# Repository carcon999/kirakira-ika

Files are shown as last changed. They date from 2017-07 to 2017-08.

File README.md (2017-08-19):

きらきら☆いか
===================

### 概要

『きらきら☆いか』は、残像表示が得意なLEDバーになります。

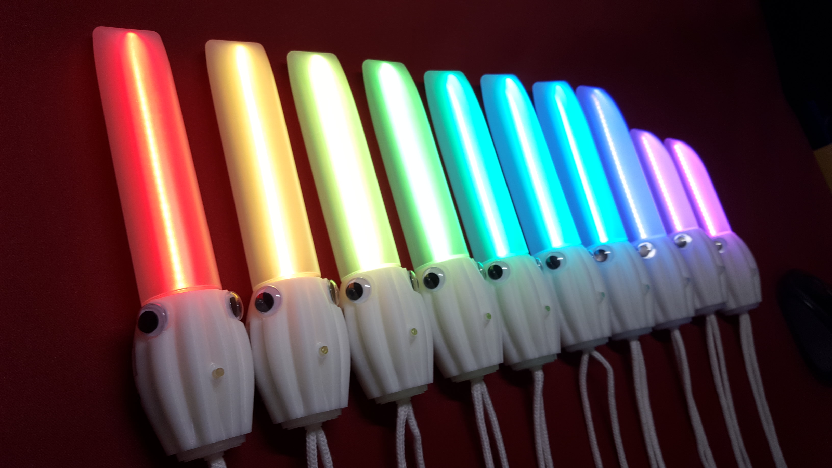
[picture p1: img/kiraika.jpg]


簡単な紹介動画はこちらです。
https://youtu.be/-Ymk3oiKI8k

### 取扱い説明書
本体の説明書になります。
[guidebook](https://github.com/carcon999/kirakira-ika/tree/master/guidebook)フォルダにPDFファイルを公開しています。  

### 回路図
ハードウェアの回路図を公開しました。
ESP-WROOM-02(ESP8266)を利用しています。LEDは3535サイズの[SK6812MINI](https://cdn-shop.adafruit.com/product-files/2686/SK6812MINI_REV.01-1-2.pdf)を利用しています。表裏合わせると最大64個のLEDを搭載できる設計です。  
[schematic](https://github.com/carcon999/kirakira-ika/tree/master/schematic)フォルダにPDFファイルを公開しています。 

### ガーバー
基板製造用のgerberを公開しました。
[gerber](https://github.com/carcon999/kirakira-ika/tree/master/gerber)フォルダに一式公開しています。基板を３面付けしたデータを公開しています。表示するには、別途Gerber Viewerが必要です。

### プログラム（本体ソースコード）
Arduino IDEでビルド可能な、本体プログラムを公開しています。
[source](https://github.com/carcon999/kirakira-ika/tree/master/source)フォルダに一式公開しています。
ビルド方法は、その中にある[README.md](https://github.com/carcon999/kirakira-ika/tree/master/source/README.md)を参照してください。

### 筐体モデルデータ
モデリングした本体の筐体データを公開しました。  
[3dmodel](https://github.com/carcon999/kirakira-ika/tree/master/3dmodel)フォルダにSTLファイルを公開しています。  
３Dプリンタで印刷することができます。  

### きら☆いか リモコン
アンドロイド端末で利用できるWi-FiリモコンはGoogle Playから[ダウンロード](https://play.google.com/store/apps/details?id=jp.gr.java_conf.approid.kiraika_remo)することができます。  

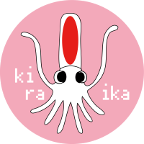
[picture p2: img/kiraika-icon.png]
  

### リモコン用ソースコード  
リモートコントロールは、 **WebSocket**が利用できるため、ブラウザ経由で制御することができます。[remotecontrol](https://github.com/carcon999/kirakira-ika/tree/master/remotecontrol)フォルダに一式公開しております。動作確認は、Chromeでのみ確認しております。
PCのWi-Fi接続先をきらきら☆いかのアクセスポイントにすることで、パソコンからコントロールすることができます。  
※こちらは、本体用のプログラムではありません。リモートコントロール用です。

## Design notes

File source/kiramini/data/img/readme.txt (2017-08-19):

画像はこのimgフォルダに配置された画像が有効になります。
有効な画像には条件がありますのでご注意ください。

１．ファイル名は、８＋３の短い名前を利用してください。
２．画像は、24bitフルカラービットマップ形式のみです。（PNGやJPGはNG)
３．画像の高さは、LED数に合わせてください。
４．画像の幅は、最大256ピクセルとします。

デフォルトで入っている画像は、下記のサイトのアイコンを一部利用させていただきました。
手頃なサイズのアイコンが揃っております。
ソザイガロー（SozaiGaro）様
http://hpgpixer.jp/

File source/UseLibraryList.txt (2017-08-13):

Use Library List

*** Arduino core for ESP8266 WiFi chip

https://github.com/esp8266/Arduino
GNU Lesser General Public License version 2.1 or (at your option) any later version.

*** ESP8266WebServer

https://github.com/esp8266/Arduino/tree/master/libraries/ESP8266WebServer

Copyright (c) 2014 Ivan Grokhotkov.
GNU Lesser General Public License version 2.1 or (at your option) any later version.

*** Software I2S library for esp8266

Copyright (c) 2015 Hristo Gochkov.
GNU Lesser General Public License version 2.1 or (at your option) any later version.

*** Library for accelerometer_MMA7760

Copyright (c) 2013 seeed technology inc.
MIT License (MIT)

*** ArduinoJson

https://bblanchon.github.io/ArduinoJson/
MIT License (MIT)

*** WebSocket Server and Client for Arduino

https://github.com/Links2004/arduinoWebSockets
GNU Lesser General Public License version 2.1 or (at your option) any later version.

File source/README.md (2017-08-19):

ビルド＆書き込み手順の説明
===================

### 注意事項

ライセンスは、[LICENSE.txt](https://raw.githubusercontent.com/carcon999/kirakira-ika/master/LICENSE.txt)をご確認ください。

# 概要

プログラムは、Arduino IDE 1.8.2でビルドし動作確認しています。  
ファームウェアを変更するには、ライブラリの準備や本体のジャンバー設定を変更する等の準備が必要になります。
手順をしっかり確認してから実施してください。ファームウェアの書き換えにはリスクを伴います。自己責任で実施してください。  

# ビルド環境の構築

## Arduino IDEをインストールする

IDEのインストール方法については、「Arduino IDE インストール」で検索することで見つけることができますので、
その手順に従ってインストールしてください。  当方では、Arduino IDE 1.8.2で検証しています。

インストール後、今回利用しているマイコンESP-WROOM-02(ESP8266)が利用できるように、ボードマネージャーにESP8266ボードをインストールする必要があります。
こちらも、ここでは詳細な説明をしませんので、「Arduino IDE ESP8266 インストール」で検索しインストールしてください。  

今回利用したバージョンは、「esp8266 by ESP8266 Commuity Version 2.3.0」になります。

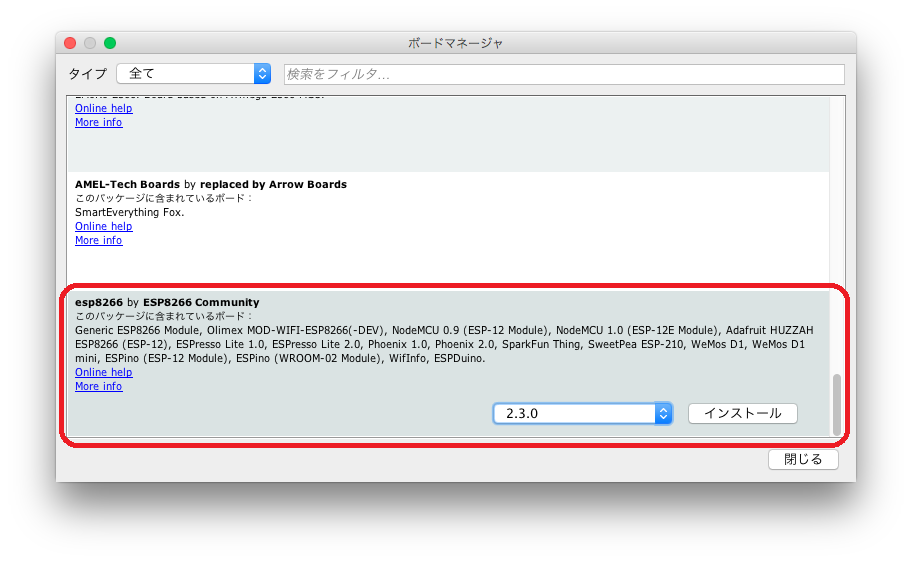
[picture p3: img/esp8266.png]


## ライブラリをインストールする

次に、利用するライブラリを２つ追加します。  
IDEの「スケッチ」→「ライブラリをインクルード」→「ライブラリを管理」を選択し、以下の２ライブラリをインストールします。

* ArduinoJson by Benolt Blanchon
* WebSockets by Markus Sattler 

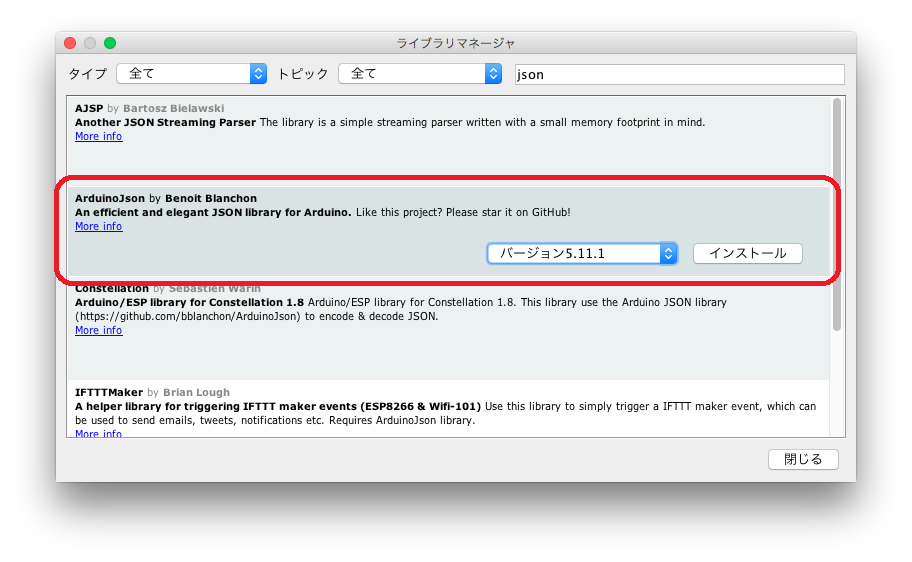
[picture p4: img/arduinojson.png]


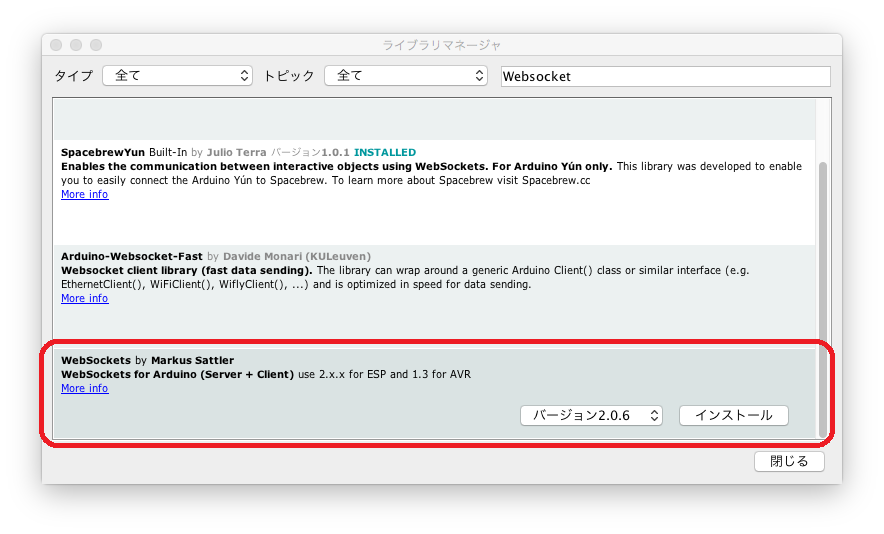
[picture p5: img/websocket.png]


## データ領域書き込みツールのインストール

データ領域（残像用の画像や設定HTMLファイル）に書き込むためには、ツール（[SPIFFSファイルシステムアップローダー](https://github.com/esp8266/arduino-esp8266fs-plugin)）
をインストールする必要があります。ツールをインストールすることで、Arduino IDEからデータ領域にデータを書き込むことができるようになります。

[SPIFFSファイルシステムアップローダー](https://github.com/esp8266/arduino-esp8266fs-plugin)をインストールしますが、インストーラは存在しないので、手動でファイルをコピーする必要があります。
幸い詳しく手順を説明しているブログがありますので、こちらを参考にしてください。

https://www.mgo-tec.com/spiffs-filesystem-uploader01-html

注意点としては、配置先の階層とフォルダ名に注意してください。下記の写真のような階層です。(画面はMacの場合です）

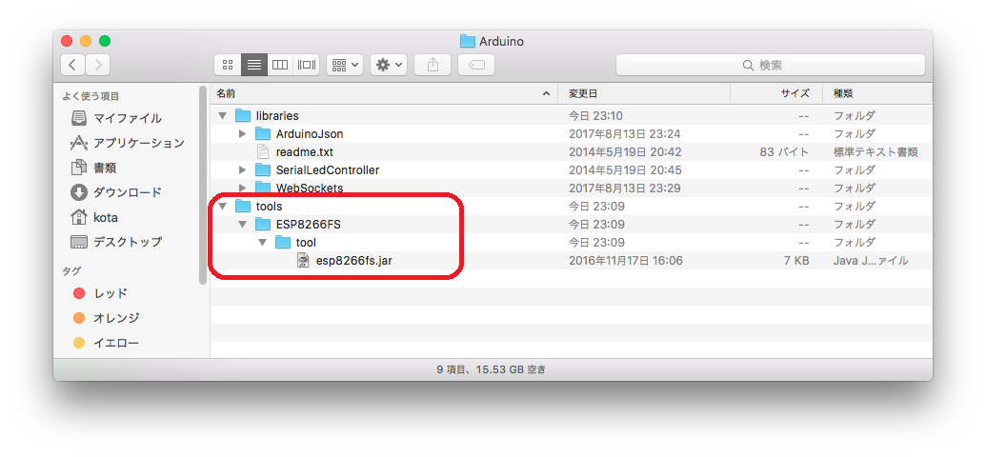
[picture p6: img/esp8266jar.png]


配置後、IDEを起動（再起動）すると、ツールメニューの中に「ESP8266 Sketch Data Upload」表示されるようになります。

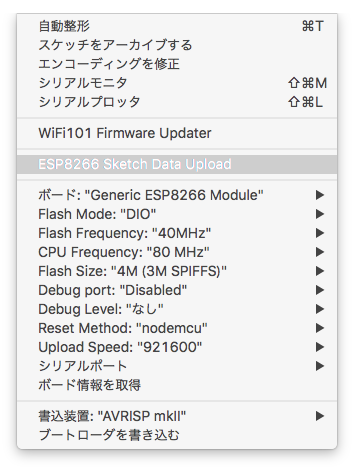
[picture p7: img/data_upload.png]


以上でツール類のインストールは全て完了しました。

# 本体側の準備（基板の取り出しとジャンパー変更）

micro USBケーブルで本体とパソコンを接続し書き換えを行いますが、そのままの状態では書き換えは行えません。
基板上のジャンパー設定を変更した上で書き換えを実施する必要があります。そのためには、本体から基板を取り出す必要がありますが、
無理な力をかけて取り出すと故障の原因ともなりますのでご注意ください。

1. 本体の電源はOFFとなっていることを確認します。

2. ネジを２か所外し、背面カバーを外します。

3. 基板を取り出します。（チューブを5度程度折り曲げると取り出しやすいです。）
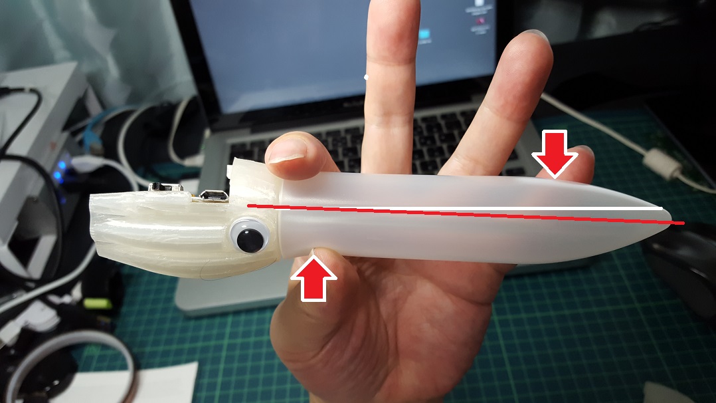
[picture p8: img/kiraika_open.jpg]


4. 取り出した基板の前面に小型のジャンパーがあり、現在は、LED側となっているのをRX側にします。
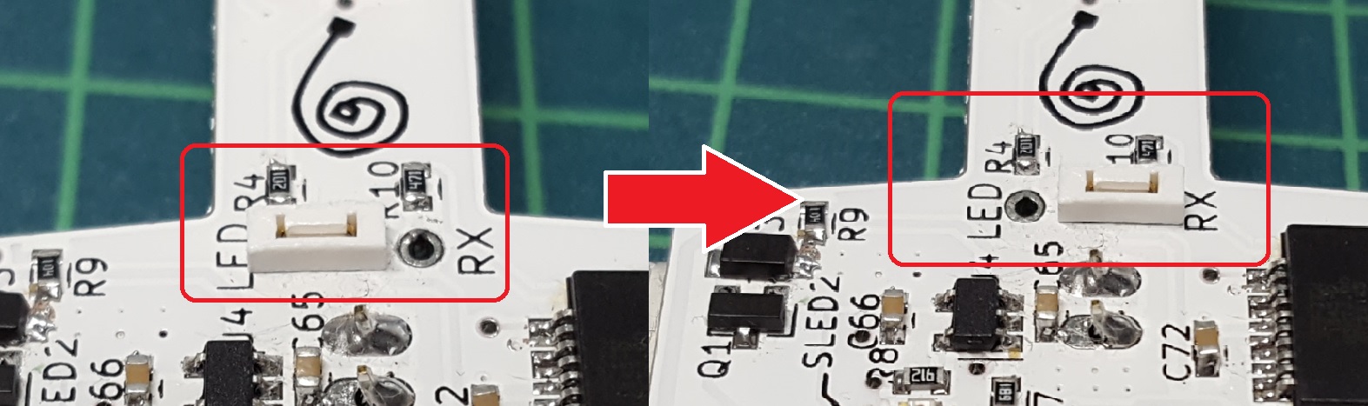
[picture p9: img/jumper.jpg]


では書き換えましょう！

# Flash領域の説明と全体の手順

### Flash領域の説明

ESP8266に内蔵されたFlashROMは、プログラム用に１Mバイト、データ用の３Mバイトとして定義されています。

現在は、プログラム領域は、USB（シリアルポート）経由で書き込みし、データ領域書き込みは、Wi-Fi経由のOTA（Over The Aire ）で書き込みを推奨とします。

※OTAで書き込みする場合は、プログラム領域にOTA用のプログラムが書き込まれている必要があります。

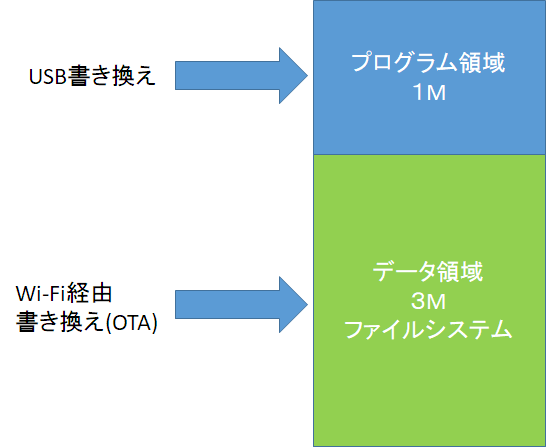
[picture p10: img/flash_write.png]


もし、プログラム領域だけ書き換える必要がある場合は、STEP3へ進んでください。

### 全体の手順

少し複雑な手順になりますのでじっくりとすすめてください。

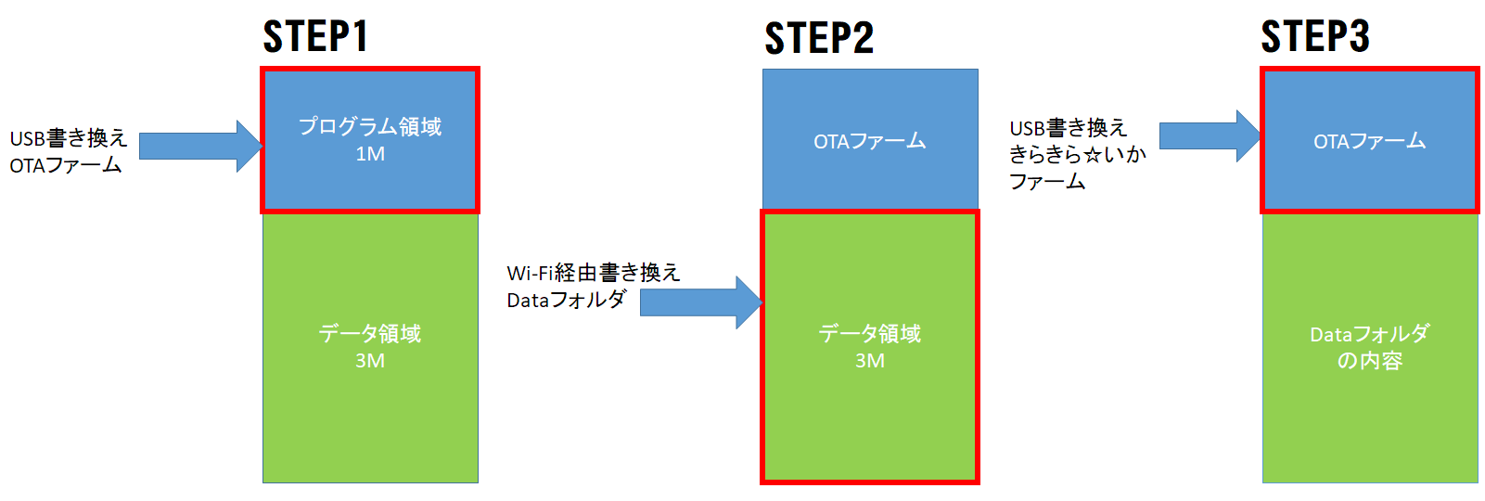
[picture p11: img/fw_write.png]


* STEP1 OTAのファームをUSB経由で書き込む。

* STEP2 ネットワーク経由でDataを書き込む。

* STEP3 きらきら☆いかのファームをUSB経由で書き込む。

# STEP1 OTAファームをUSB経由で書き込む。

### OTAのファームを準備する。

OTAのファームは、スケッチ例に入っている「BasicOTA」を利用します。

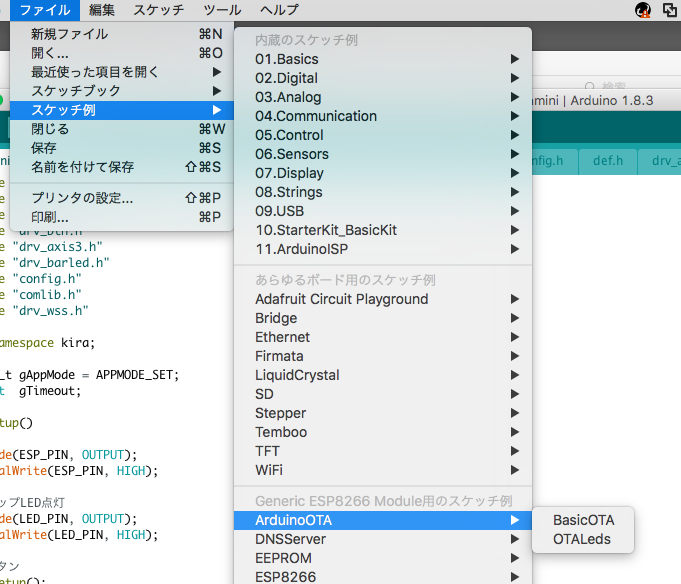
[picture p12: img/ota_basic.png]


ただし、一部コードを修正する必要があります。

BasicOTAを開き、ssidとpasswordの値をご自身のWi-Fi環境の値に変更します。

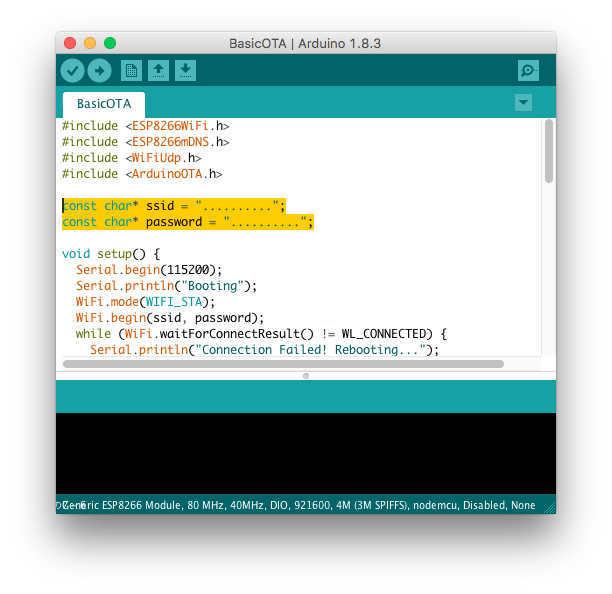
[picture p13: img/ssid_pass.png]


変更したら、名前を付けて保存します。場所は、ご自身が分かり易い場所に保存してください。名前はなんでも構いませんが、BasicOTA_Kiraとでもしておきましょう。
この例では、デスクトップにBasicOTA_Kiraで保存しています。

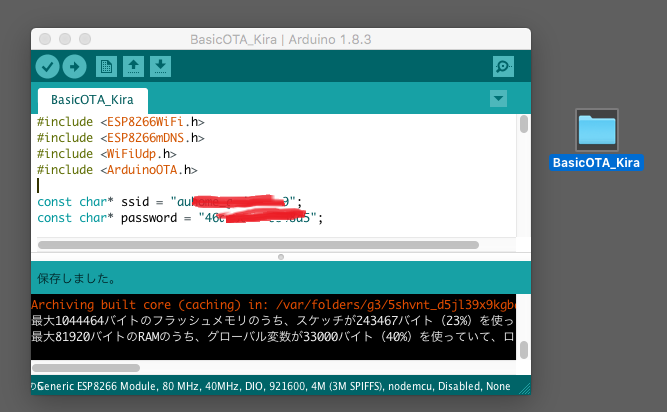
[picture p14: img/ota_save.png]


次に、書き込むデータをBasicOTA_Kiraのフォルダ直下にコピーします。データは、配布しているソースコードの一式中にdataフォルダがありますので、
そのフォルダ毎すべて直下にコピーします。（下記の写真のように）

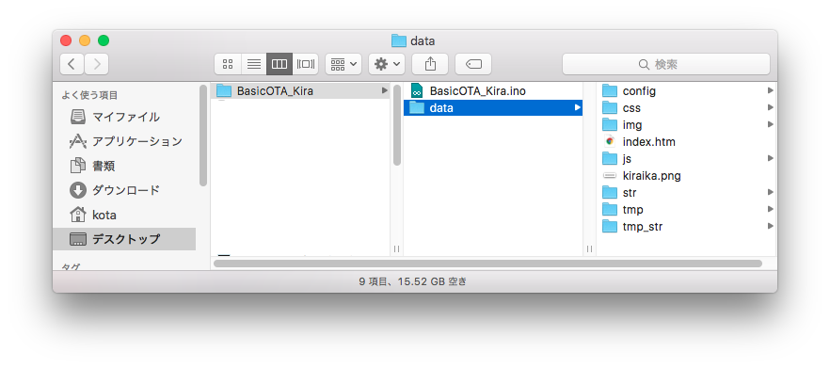
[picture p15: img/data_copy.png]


### OTAのファームを書き込む。

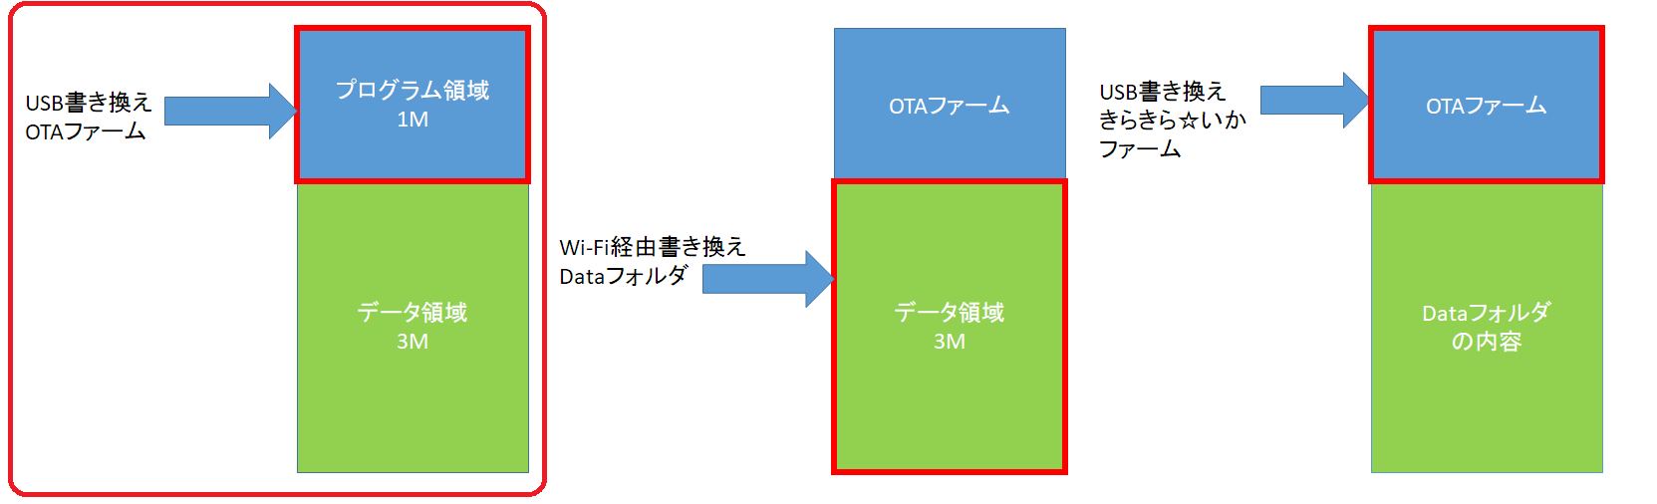
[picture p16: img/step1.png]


0. IDEのプロジェクトは、BasicOTA_Kiraが開かれている状態とします。

1. 電源がOFF状態で、ジャンパーがRX側になっているのを確認します。

2. microUSBケーブルを接続し、PCと接続します。

3. 本体の電源を入れます。（LEDバーは点灯しません。）

4. IDEのシリアルポートを合わせます。

5. 書込みボタンを押して書き込みます。

6. 書込みが100%で完了したらOKです。

# STEP2 ネットワーク経由でDataを書き込む。

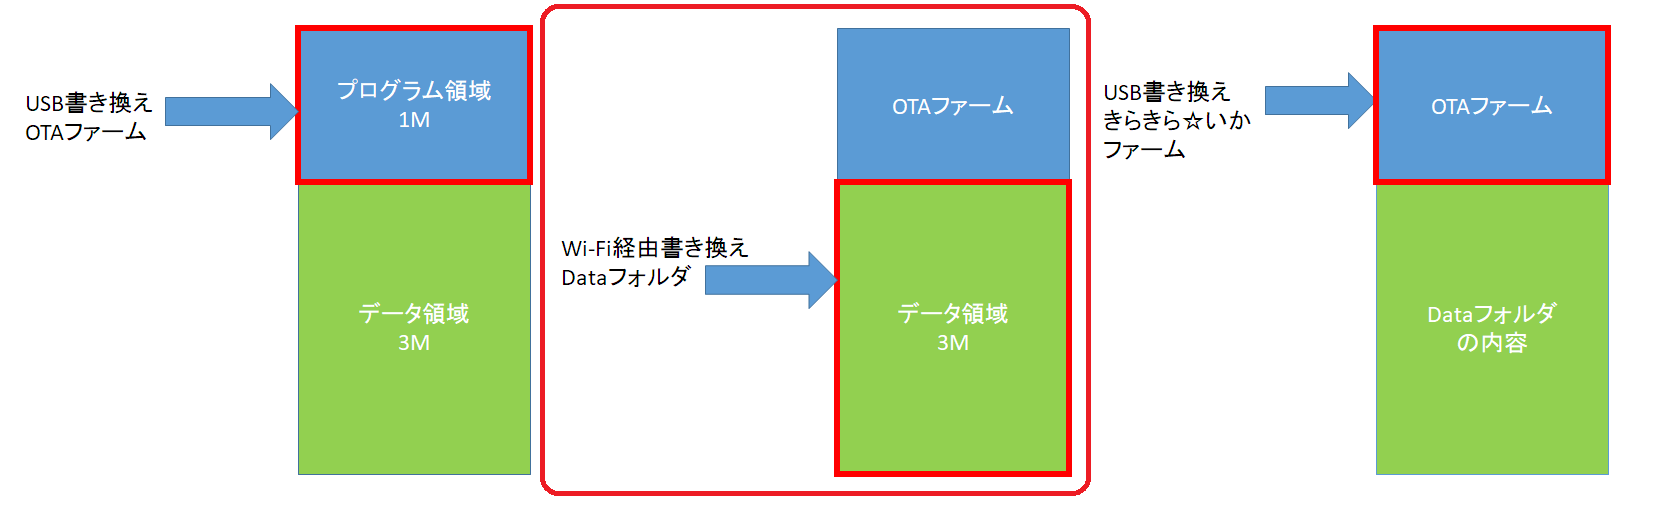
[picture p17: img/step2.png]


0. STEP1の直後とします。

1. IDEを再起動(IDEを閉じて、もう一度BasicOTA_Kiraを開く)します。（これ重要）　本体はそのままでOKです。

2. 「ツール」→「シリアルポート」の中にネットワークのアドレスが表示されているはずなので選択します。

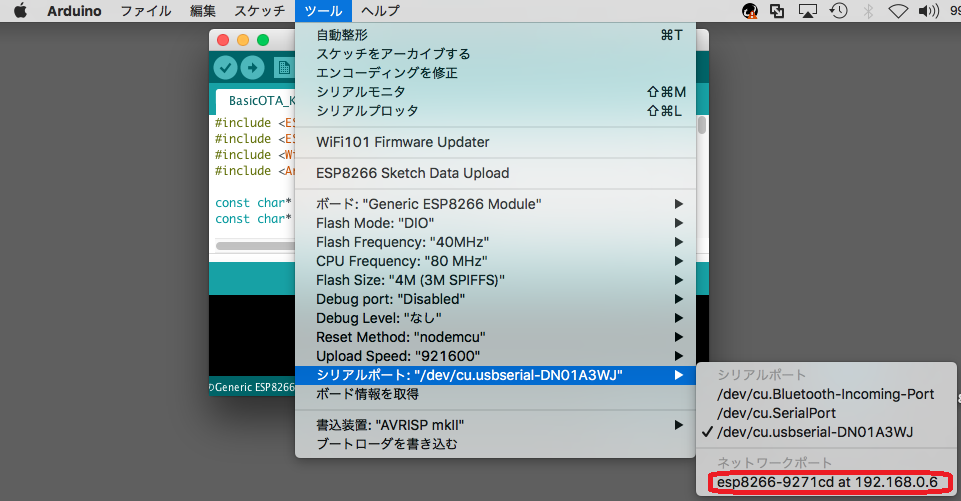
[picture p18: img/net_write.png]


※もし、表示されてない場合は、本体の電源をOFF->ONして、IDEを再起動してみてください。

3. 「ツール」→「ESP8266 Sketch Data Upload」を選択します。画面に何も変化がありませんが、約30秒くらい待ちます。

4. 下記のような画面がでればデータ書込み成功です。「SPIFFS Image Uploaded」

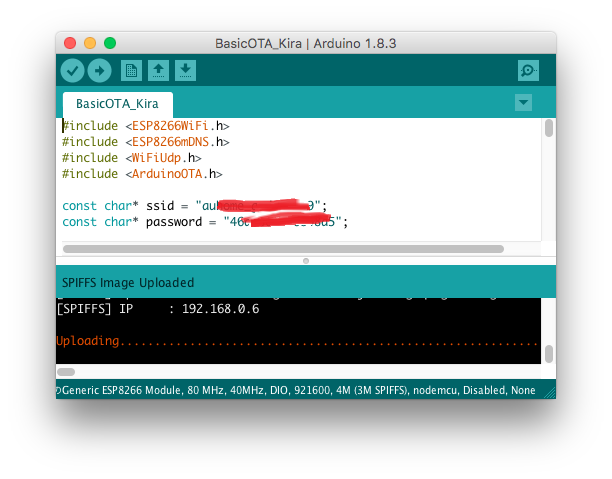
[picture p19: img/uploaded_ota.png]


# STEP3 きらきら☆いかのファームをUSB経由で書き込む。

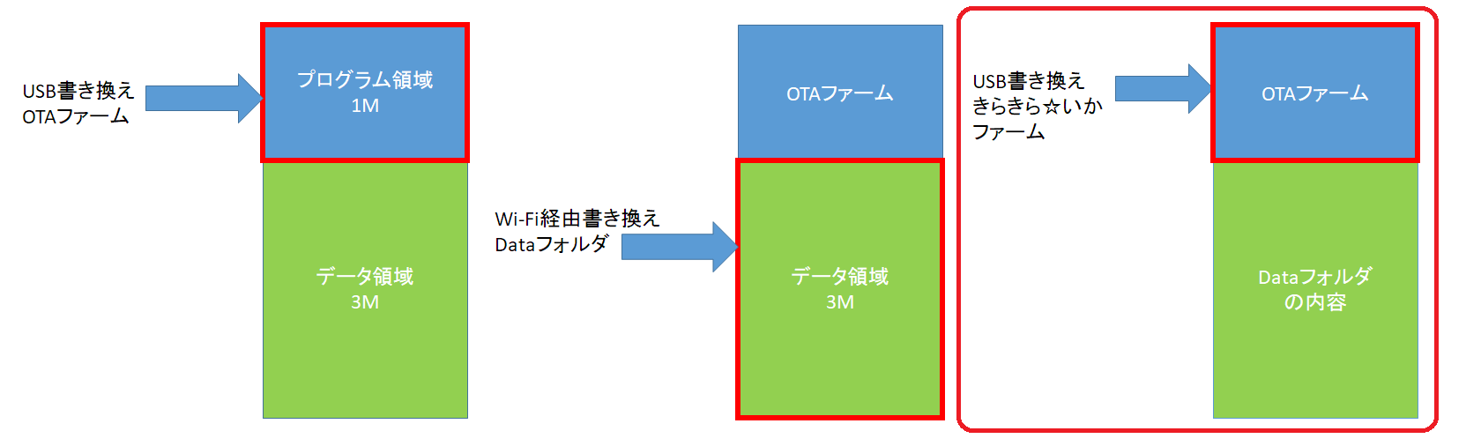
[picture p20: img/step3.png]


0. 電源がOFF状態で、ジャンパーがRX側になっているのを確認します。

1. microUSBケーブルを接続し、PCと接続します。

2. 本体の電源を入れます。（LEDバーは点灯しません。）

3. IDEで、きらきら☆いかのファームを開きます。（[kiramini](https://raw.githubusercontent.com/carcon999/kirakira-ika/master/source/kiramini)フォルダ内のkiramini.inoを開きます。）

4. シリアルポートをUSBの仮想シリアルポートに合わせます。（ネットワークじゃない方）

5. IDEの書き込みボタンを押します。

6. もし失敗した場合は、本体の電源をOFF－＞ONし、再度書き込みボタンを押してください。

7. 繰り返し失敗する場合は、手順が間違っている可能性があります。再度手順（4～8）を確認してください。

8. 書き込みに成功（100%)したら、本体の電源を一度OFFにし、USBケーブルを外します。

9. 小型ジャンパーをLED側に戻し、本体の電源を入れて動作確認します。

10. 上手く動作したら電源をOFFにして、筐体に戻します。

# 最後に

新しいファームウェアがリリースされた場合は、各種設定ファイル（データ領域に配置）も新しくなっている場合があります。
基本的に、STEP1,STEP2,STEP3の順で実施してください。また、上手く起動しない場合も、データ領域を書き換え直して試してみてください。

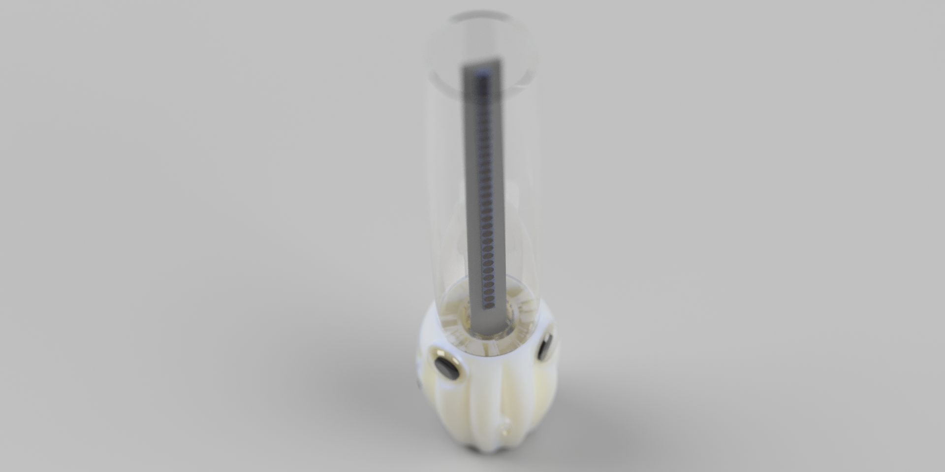
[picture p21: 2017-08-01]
img/kirakira-ika-cg.png

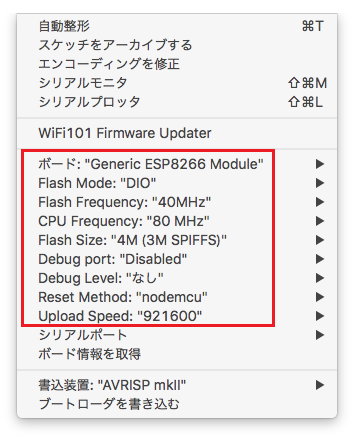
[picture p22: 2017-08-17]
img/setting.png

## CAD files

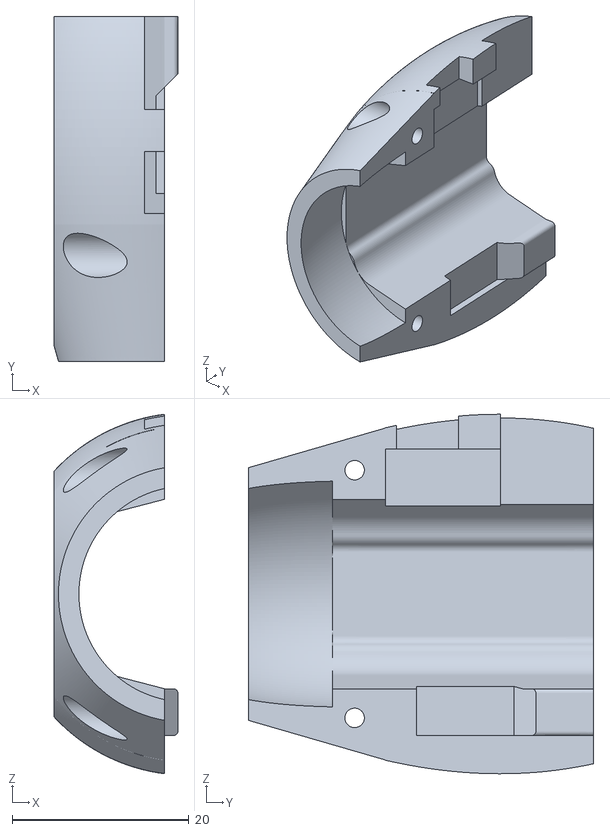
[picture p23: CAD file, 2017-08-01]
3dmodel/kiraika-cover.stl
14.0 x 39.0 x 40.6

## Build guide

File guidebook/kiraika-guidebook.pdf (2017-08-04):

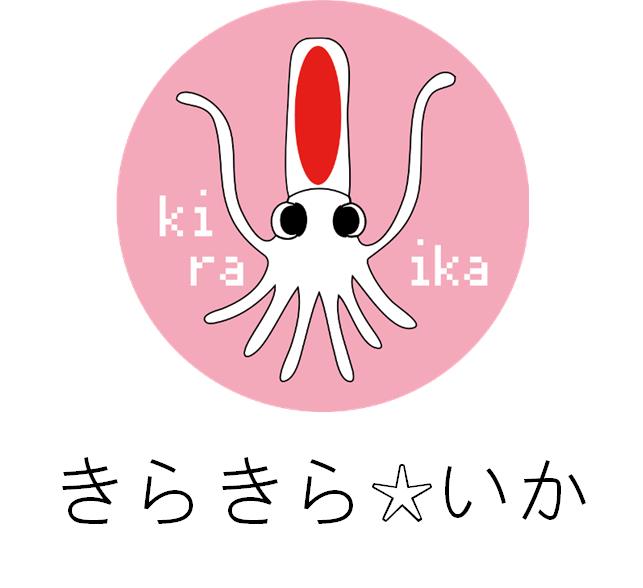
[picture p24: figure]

1

# 取扱説明書

0.1 版

2

## 1 はじめに

このたびは、「きらきら☆いか」（以降“本体”）をお買い上げいただきありがとうございます。残像で画像を表

示することが得意なガジェットになります。製品のタイプにより、LED の搭載個数が異なりますが、基本的な操作

は同一になりますので、必要に応じて読み替えてください。

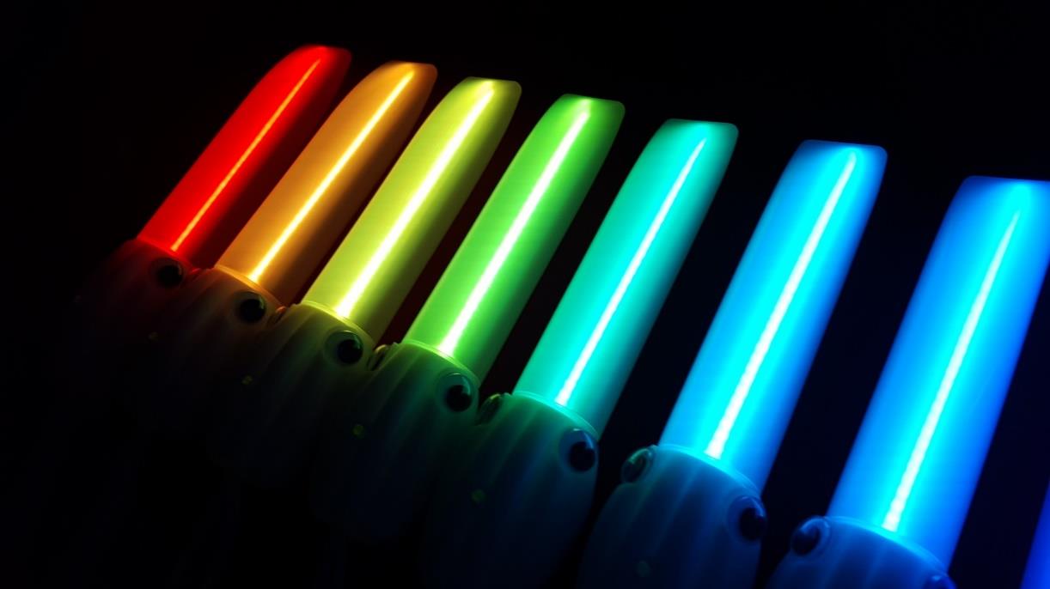
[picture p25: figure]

写真 1-1 きらきら☆いか本体

## 2 注意事項

ご利用の前に注意事項をお守りください。

- 泳げませんので水中や雨の中でのご利用はお止めください。
- 強いショックを与えないでください。（ある程度は大丈夫です。）
- ご利用はご自身の責任の範囲でお願いいたします。
- 多分無いとおもいますが、食べると身体に悪影響を及ぼします。万一、飲み込んだら、すぐに医師にご相

談ください。

- 振ったり、振り回したりして確認する場合は、周囲の人やモノがないことを確認した上でご確認ください。そ

の場合に怪我や破損が発生しても責任は負いません。十分注意してください。

- 充電は必ず目の届く場所で行ってください。

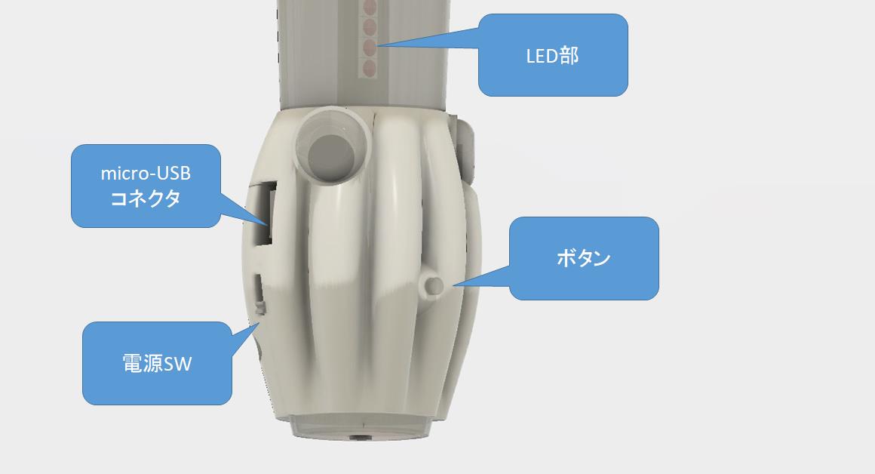
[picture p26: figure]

3

## 3 名称

図 3-1 名称一覧

## 4 電源の入れ方

LED 部を上に向けて電源 SW を上にスライドさせてください。

約３秒後に点灯します。（初回は赤で点灯します。）

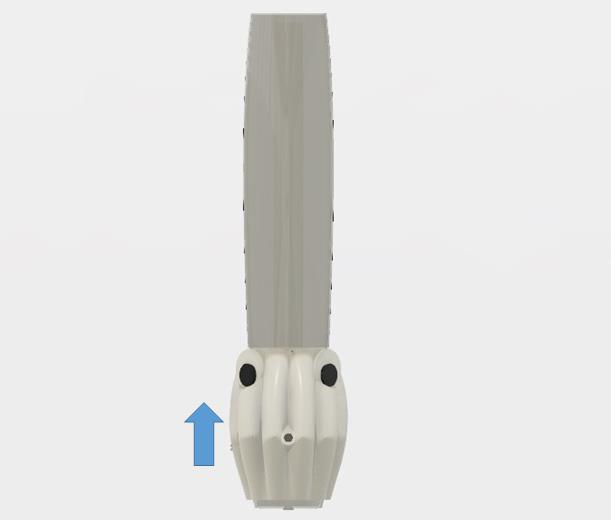
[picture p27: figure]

図 4-1 電源を入れる際の本体の向き

4

## 5 電源の切り方

電源 SW を下にスライドさせてください。

## 6 動作・表示の切り替え方

ボタンを押すことで、表示を切り替えることができます。表示は下記のように切り替わります。画像表示中は

画像送りとなり、全画像を表示終えると単色表示へ戻ります。

図 6-1 表示切り替え

### 6.1 画像表示の手動／自動

画像表示中に、ボタンを長押し（3 秒以上）することで、手動表示／自動表示の切り替えが行えます。手

動は左右の振りに合わせて表示されますが、自動は振りに関係なく連続して表示されます。

5

## 7 充電の仕方

本体の電源を OFF の状態で micro-USB ケーブルを接続して充電します。充電中は、本体の持ち手部分が

赤く点灯しています。

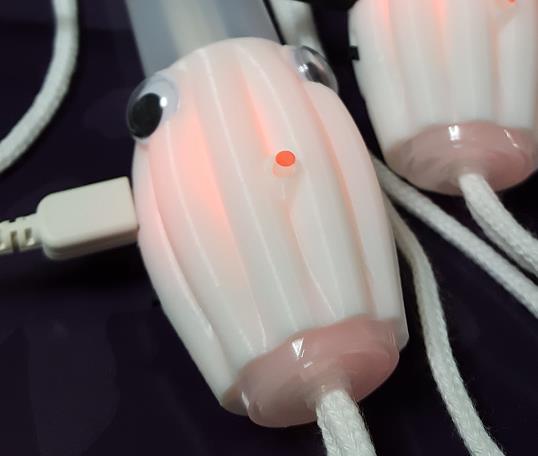
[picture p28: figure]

写真 7-1 充電中の本体色

充電が完了すると消灯します。電池の利用状態にもよりますが、１時間から２時間程度かかります。念のた

め目の届く場所で充電します。異常な発熱や、２時間以上充電している場合は、ご利用を中止してください。

※本体の電源を ON にしたままでパソコンへ接続してご利用するのはお止めください。もし、充電しながら本体を

利用する場合は、モバイルバッテリー等での利用としてください。

6

## 8 設定変更

設定変更は、本体に Wi-Fi で接続し変更します。Wi-Fi 接続できる外部装置（PC、スマートフォンなど）

が必要になります。

図 8-1 設定変更の流れ

### 8.1 本体の設定機能有効化

本体の電源を一度切り、LED バーの上部を地面に向ける方向で電源を入れます。

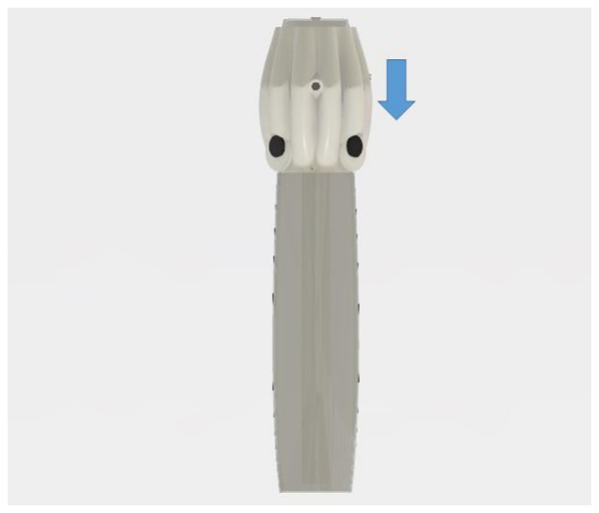
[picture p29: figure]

図 8-2 設定機能有効化の際の本体向き

３秒ほどそのままの方向を維持すると、LED バーが白で点灯します。本体の角度を変更すると、角度に応じ

て LED 全体が赤、緑、青に変化します。全体が赤で点灯している角度で、本体のボタンを押します。設定機

能が有効になっていれば、LED が一つだけ赤で点灯状態になります。

### 8.2 WI－FI 接続

設定機能が有効になると、本体が Wi-Fi アクセスポイントとして見えます。PC やスマートフォンの Wi-Fi 設定

で接続先を探してみると、「KIRA-XXXXXX」（XXXXXX は、任意の英数字）が見つかりますので、接続するよう

7

にします。接続する際のパスワードは固定で「kirakira123」となっています。もし、Wi-Fi アクセスポイントが見つか

らないようであれば、電源を一度切り、再度本体の設定機能有効化を行ってみてください。

※Wi-Fi で接続中は、インターネットには接続できません。

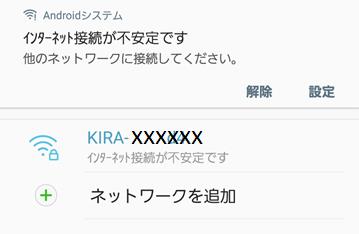
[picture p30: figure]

図 8-3 ネットワーク設定例

### 8.3 ブラウザで設定

PC、スマートフォンなどのブラウザ（Chrome 推奨）で「http://192.168.10.1/」にアクセスします。多少時間

がかかる場合がありますので、10 秒程度お待ちください。20 秒以上アクセスできない場合は、リロードをお試しく

ださい。

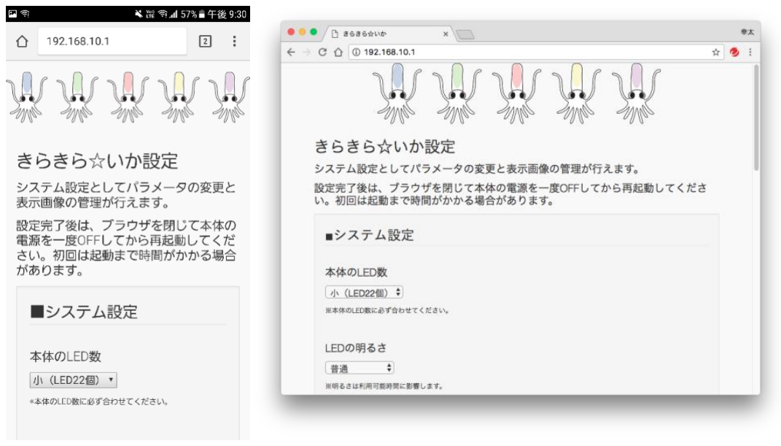
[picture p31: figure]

図 8-4 ブラウザでの設定画面例

8

### 8.4 システム設定

システムの設定変更が行えます。システム設定変更後は、きらきら☆いか本体の再起動が必要です。ブラウ

ザから変更操作を終えた後に、本体のボタン押下もしくは、一度電源を OFF→ON してください。確定処理中

は、次回起動時に時間がかかる場合があります。そのままでお待ちください。赤の LED が下から上に点灯→消

灯を繰り返すような表示となります。この再起動中の電源 OFF は行わないでください。画像の再構築が行われ

ファイル書き換えが行われています。

8.4.1 本体の LED 数
実装されている前面の LED 数と一致するようにします。ご購入時には一致する設定となっています。

8.4.2 LED の明るさ
明るさを変更します。ご利用時間の電池持ちに影響します。“普通”でのご利用を推奨します。デフォルトは

“普通”です。

8.4.3 Wi-Fi リモコンの利用
本体を起動する際に、Wi-Fi リモコンが利用できるようにアクセスポイント有無を指定できます。リモコンを利用

しない場合は、OFF とすると電池持ちが多少良くなります。デフォルトは、ON です。

### 8.5 画像ファイルアップロード

新しい画像を追加することができます。画像は 24bit フルカラービットマップ形式(*.bmp)のみサポートしていま

す。画像の高さは、本体の LED 数に合わせてください。幅の最大 256pix になります。つまり、22x256 もしくは、

32x256 のサイズが最大です。ファイル名は、8+3 の短い名前でアップロードしてください。同一名称の場合は、

上書きされます。画像は、ファイル名をソートして昇順で表示されますので順序を意識する場合はファイル名を

工夫します。

### 8.6 画像ファイル削除

ファイルを選択して削除することができます。

9

## 9 きら☆いか リモコン（WI-FI リモコン）

Wi-Fi でコントロールできるリモコンを提供しています。現在は Android 版のみ提供しております。Google

Play からダウンロードしてご利用ください。Android 端末 4.1 以上で動作します。

※2017/08/03 時点では、iPhone 版はございません。

https://play.google.com/store/apps/details?id=jp.gr.java_conf.approid.kiraika_remo&hl=ja

https://goo.gl/D5LZpe （短い URL）

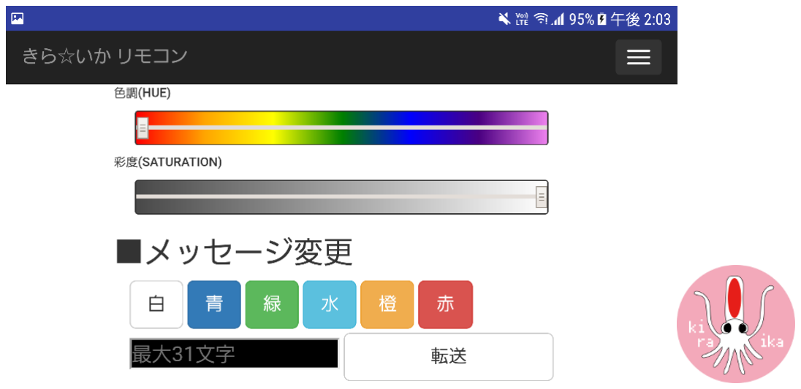
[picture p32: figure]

図 9-1 画面とアイコン

画像の切り替え操作や、起動直後の本来色の変更、表示メッセージ（文字）の変更も行えます。

### 9.1 リモコンの機能

Wi-Fi リモコンで操作できる機能は以下になります。

# | 機能 | 説明

10

1 | 画像送り・戻し | 次画像への変更、前画像への変更ができます。
2 | 画像表示変更 | 手動／自動の表示切り替えができます。
3 | 単色変更 | 本体起動直後の表示色を変更できます。
4 | メッセージ変更 | 通知メッセージを変更できます。音声入力も可能です。

### 9.2 WI-FI 設定方法

アプリ起動前に、Wi-Fi 接続設定を行います。8.2Wi－Fi 接続の接続設定を行います。

### 9.3 起動方法

先の Wi-Fi 設定が終わっている状況で、アプリを起動すると自動的に本体と接続します。

### 9.4 注意事項

Wi-Fi は通信状況により切断される場合があります。通信できない状況が発生した場合は、右上の接続処

理を手動で実施してください。（切断 －＞ 接続を行います。）

11

## 10 オープンソース

GitHub にて各種データを公開します。

https://github.com/carcon999/kirakira-ika

https://goo.gl/72r9ny (短い URL)

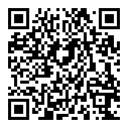
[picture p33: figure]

※一部準備中のもがございますので、完全公開までしばらくお待ちください。

## 11 Q&A

表 11-1 Q&A 一覧

＃ | 質問 | 回答
１ | フル充電でどれぐらいの時間使えます か？ | LED 数と明るさ、利用する色で変化します。赤 LED を常時 点灯させた場合、普通の明るさで、30～60 分程度利用で きます。
２ | 充電時間はどれぐらいですか？ | 約１時間です。
３ | 利用できる時間を長くすることはできま すか？ | 簡単なのは明るさを抑えることで長持ちします。利用している 充電池が 110mAh と小型で小さいものを利用しているので 容量の大きいものにすることで長持ちさせることも可能です。
４ | 自分でビットマップを作るのが大変なの でダウンロードできませんか？ | 当方も利用させていただきましたが、こちらのサイトが無料で ご利用いただけます。ソザイガロー（SozaiGaro）様 http://hpgpixer.jp/
５ | 自分で改造・改版してもいいですか？ | 構いません。オープンソースでご提供しています。一応ライセン スには従ってください。

12

６ | もっと長いのが欲しい！ | オープンソースですのでご自身で改良することで作ることは可
| | 能です。

## 12 変更履歴

0.1 版 2017/8/4 新規作成

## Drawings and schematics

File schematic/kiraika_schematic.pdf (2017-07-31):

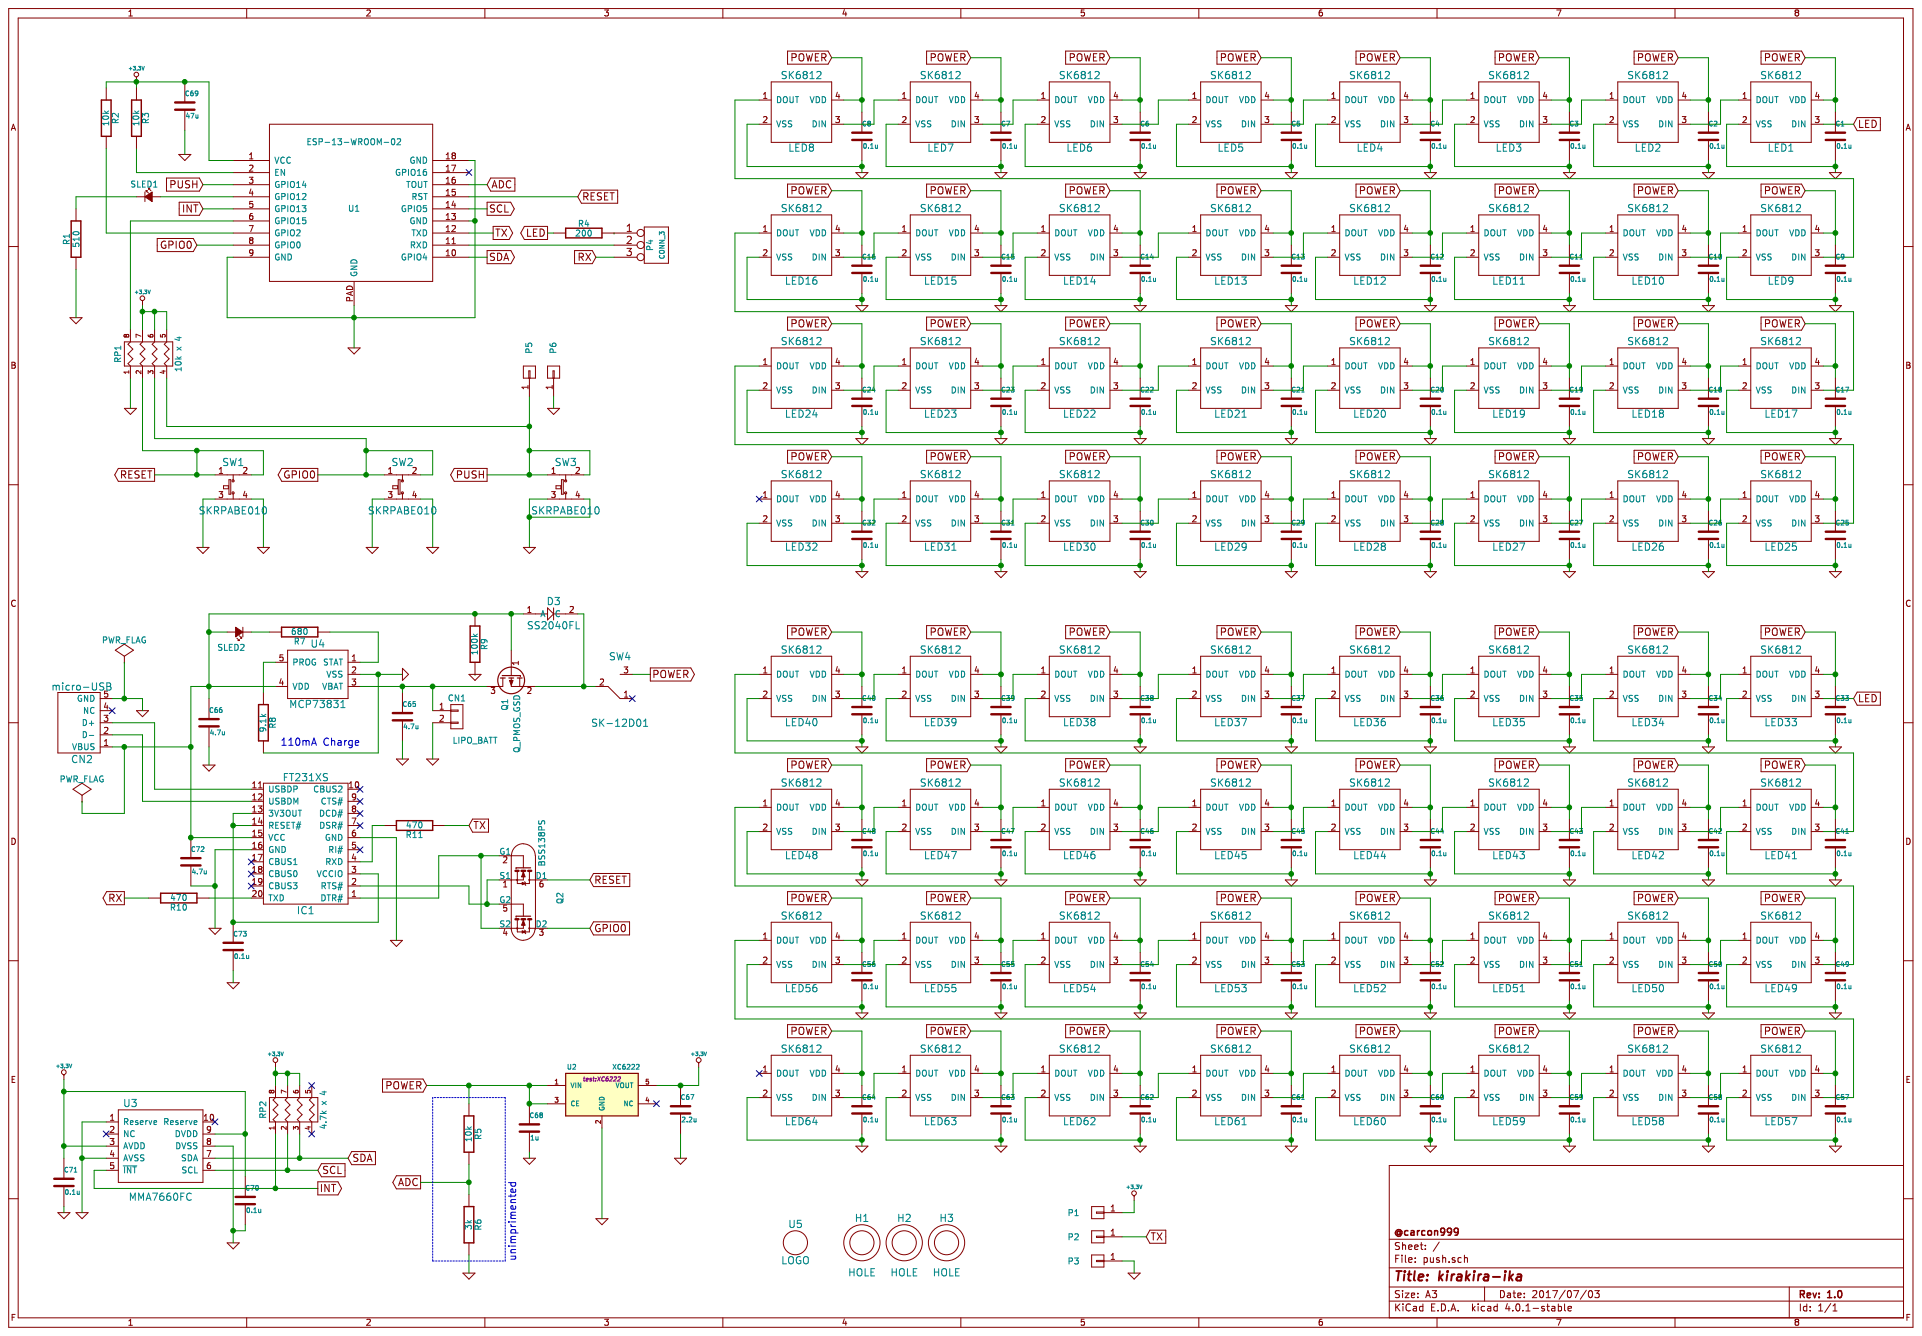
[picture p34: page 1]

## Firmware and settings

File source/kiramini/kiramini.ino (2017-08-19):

/*
 * kiramini.ino
 * きらきら☆いかメイン処理
 * 
 * スタートアップ処理＋メインループ処理の記述
 * 
 */
#include <Arduino.h>
#include "def.h"
#include "image.h"
#include "drv_btn.h"
#include "drv_axis3.h"
#include "drv_barled.h"
#include "config.h"
#include "comlib.h"
#include "drv_wss.h"

using namespace kira;

AppMode_t gAppMode = APPMODE_SET;
uint32_t  gTimeout;

void setup()
{
  pinMode(ESP_PIN, OUTPUT);
  digitalWrite(ESP_PIN, HIGH);

  // チップLED点灯
  pinMode(LED_PIN, OUTPUT);
  digitalWrite(LED_PIN, HIGH);

  // ボタン
  BTN.setup();

  USE_SERIAL.begin(115200);
  USE_SERIAL.println("\nstart");
  delay(100);

  // 設定ファイルロード
  CONF.load();

  // 3軸加速度センサー
  AX3.setup();
  // 下向きで起動した場合は設定モード
  if(AX3.get_tilt() == TILT_DOWN)
  {
    // 設定モードへ
    startup_setting_mode();

  // 通常起動モード
  }else{
    // 通常モードへ
    startup_normal_mode();
  }
}

// 設定モードへの移行初期化
void startup_setting_mode(void)
{
  USE_SERIAL.println("Setting Mode.");

  LED.end();

  // Wi-Fiリモコン 停止設定
  ws_remo_enabled(false);
    
  // フルカラーLED初期化
  LED.begin(CONF.length);

  // 設定モード
  kr_setting_start();
}

// 通常モードへの移行初期化
void startup_normal_mode(void)
{
  USE_SERIAL.println("Normal Mode.");

  // Wi-Fi設定中はLEDバーは停止する。
  LED.end();

  // Wi-Fiセットアップする。
  ws_remo_enabled(CONF.wifi != 0);
  
  // フルカラーLED初期化
  LED.begin(CONF.length);

  // 更新が必要な場合は、ファイルの生成処理を実施する。
  if(CONF.update){

    USE_SERIAL.println("export start");
    IMG.export_use_file(CONF.bright, true, export_callback);
    IMG.create_string_file(CONF.bright);
    USE_SERIAL.println("export end");
      
    // フラグクリアし設定ファイル保存
    CONF.update = 0;
    CONF.save();
  }

  // 単色表示モード
  kr_color_start(false);
}

// 進捗表示
static void export_callback(void)
{
  static uint8_t counter = 0;
  LED.set_progress(CONF.bright, counter++);
}

const FUNCPTR tMode[APPMODE_NUM] = {
  loop_kr_setting,
  loop_kr_color,
  loop_string,
  loop_image
};

void loop()
{
  (*tMode[gAppMode])();

  // Wi-Fiリモコン処理
  ws_remo_loop();
}

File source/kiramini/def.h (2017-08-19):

/*
 * def.h
 * マクロ定義
 * 
 * システムの定数定義する。
 */

#ifndef DEF_H
#define DEF_H

#define null         NULL
#define LED_MAX_LENGTH    (32)
#define LED_RGB_SIZE      (3)

// UARTデバッグ出力をする場合は、trueにする。
#define UART_DEBUG false

#define USE_SERIAL Serial

#define LED_PIN       12  // チップLED出力

#define ESP_PIN       15  // ESP_PIN固有
#define SDA_PIN        4  // I2CのSDA
#define CLK_PIN        5  // I2CのCLK
#define INT_PIN       13  // I2Cの割り込み

// LEDの送信時間＋RESETを含めた時間
// 1.2us * 24bti * 32LED = 921.6us + 80us = 1001.6us　以上が必要
// 内部の処理時間やDMAのオーバヘッドを加味すると倍は必要
#define LED_DELAY     2000    // LEDの送信周期(us)

#define BRIGHT_MAX    (192)    // 最大明るさ

enum eWaitMode{
  RIGHT_WAIT,
  LEFT_WAIT
};

// 操作定義
enum eOperation{
  OP_NON,     // 操作なし
  OP_NEXT,    // 次
  OP_BEFORE,  // 戻る
  OP_MANUAL,  // 手動
  OP_REPEAT   // 繰り返し
};

enum eAppMode{
  APPMODE_SET,
  APPMODE_COLOR,
  APPMODE_STR,
  APPMODE_IMG,

  APPMODE_NUM
};

typedef enum eWaitMode WaitMode_t;
typedef enum eAppMode AppMode_t;
typedef enum eOperation OpMode_t;

typedef void (*FUNCPTR)(void);

#endif // #ifndef DEF_H

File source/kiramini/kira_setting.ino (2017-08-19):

/*
 * kira_setting.ino
 * Web設定処理
 * 
 * 設定モードの選択とWebサーバの起動
 * 
 */
#include <Arduino.h>
#include "def.h"
#include "drv_btn.h"
#include "drv_axis3.h"
#include "drv_barled.h"
#include "config.h"
#include "comlib.h"
#include "webserver.h"

using namespace kira;

enum eSettingMode{
  SETMODE_SELECT,
  SETMODE_WEB
};

typedef enum eSettingMode ModeSet_t;

static ModeSet_t mode_set = SETMODE_SELECT;

// 設定処理ループ
void loop_kr_setting(void)
{
  if(mode_set == SETMODE_SELECT){
    kr_setting_select();
  }else if(mode_set == SETMODE_WEB){
    kr_setting_web();
  }
  
  BTN.loop();
}

// 設定モード開始
void kr_setting_start(void)
{
  uint8_t rgb[LED_RGB_SIZE] = {5, 5, 5};  // 白
  LED.set_color(rgb);         // 白

  // 設定モードへ移行
  gAppMode = APPMODE_SET;
}

// 設定選択
void kr_setting_select(void)
{
  static uint8_t old_dir;
  uint8_t now_dir = AX3.get_tilt();

  //前回値と方向が異なる場合
  if(now_dir != old_dir)
  {
    // 下方向
    if(now_dir == TILT_DOWN){
      uint8_t rgb[LED_RGB_SIZE] = {5, 5, 5};  // 白
      LED.set_color(rgb);         // 白
    // 左方向  
    }else if(now_dir == TILT_LEFT){
      LED.set_color(0, 255, 5);   // 赤
    // 上方向
    }else if(now_dir == TILT_UP){
      LED.set_color(120, 255, 5); // 青
    // 右方向
    }else if(now_dir == TILT_RIGHT){
      LED.set_color(240, 255, 5); // 緑
    }
    
    old_dir = now_dir;
  }

  eButtonStatus sts = BTN.get();
    
  // ボタン押下により設定処理の実行
  if(sts == Pushed){
    BTN.clear();

    if(now_dir == TILT_DOWN){
      // 下方向

    }else if(now_dir == TILT_LEFT){
      uint8_t grb[LED_RGB_SIZE] = {0, 20, 0};  // 
      // 左方向
      LED.turn_off();
      delay(100);
      LED.set_color(0, grb);
      LED.update();
      delay(100);

      // 停止しないとWebServerが動けない場合があるので、必ずLEDは停止
      LED.end();
      // 設定ブラウザセットアップ
      WEB.setup();

      mode_set = SETMODE_WEB;

    }else if(now_dir == TILT_UP){
      // 上方向
      uint8_t grb[LED_RGB_SIZE] = {20, 0, 0};  // 
      LED.turn_off();
      delay(100);
      LED.set_color(0, grb);
      LED.update();
      delay(100);

      // WebSocketを有効に設定変更し通常モードへ
      CONF.wifi = 1;
      CONF.save();

      startup_normal_mode();

    }else if(now_dir == TILT_RIGHT){
      // 右方向
      uint8_t grb[LED_RGB_SIZE] = {0, 0, 20};  // 
      LED.turn_off();
      delay(100);
      LED.set_color(0, grb);
      LED.update();
      delay(100);

      // WebSocketを有効に設定変更し再起動する。
      CONF.wifi = 0;
      CONF.save();

      startup_normal_mode();
    }
  }

  delay(100);
}

void kr_setting_web(void)
{
  eButtonStatus sts = BTN.get();

  if(sts == Pushed){
    // 強制的にリセット
    ComLib::reset();
  }

  WEB.loop();
}

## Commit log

2017-07-31 schematic 追加
2017-08-01 筐体のデザインモデル追加
    [kiraika-cover.stl]
2017-08-01 CGのデザイン画追加
2017-08-01 Update README.md
    現在更新中であることを紹介
2017-08-01 本体の写真追加
2017-08-01 画像差し替え
2017-08-01 アプリアイコン追加
2017-08-01 Update README.md
    アンドロイドアプリのリンク公開
2017-08-01 Update README.md
    回路図と筐体モデルの公開を追記
2017-08-01 Update README.md
    紹介動画リンクを追加
2017-08-01 Update README.md
    アイコンの位置修正
2017-08-04 初版の取説追加
2017-08-04 取説を追加したので説明追加
2017-08-12 Ｗｅｂリモコンコード追加
2017-08-12 Ｗｅｂリモコンの説明追加
2017-08-13 ライブラリリストを追加
2017-08-17 説明用の画像追加
2017-08-17 説明用画像追加
2017-08-17 フラッシュの説明画像追加
2017-08-18 ソースコードの更新手順を記載
2017-08-18 ビルド手順として公開
2017-08-18 プログラムフォルダの解説追加
2017-08-19 初期ファームのソース公開
2017-08-19 公開に合わせて文言修正
2017-08-19 ガーバーの公開
    [kira_mini-B.Cu.gbl, kira_mini-B.Mask.gbs, kira_mini-B.SilkS.gbo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]
2017-08-19 ガーバーを追加し一式公開となりました。
